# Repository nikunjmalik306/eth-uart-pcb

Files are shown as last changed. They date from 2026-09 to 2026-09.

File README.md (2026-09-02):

# ETH-UART PCB

An STM32-based Ethernet-to-UART development board designed in Autodesk EAGLE.

The board combines an STM32F407VE microcontroller with a DP83848 Ethernet PHY, RJ45 Ethernet interface, USB connectivity, multiple UART interfaces, SWD programming/debug access, status LEDs, test points, and selectable configuration jumpers.

## Features

- **MCU:** STM32F407VE
- **Ethernet PHY:** TI DP83848
- **Ethernet connector:** RJ45 with integrated magnetics
- **USB:** Micro-B connector
- **UART:** UART1, UART2, UART3 and UART5 signals
- **Debug/programming:** SWDIO and SWCLK
- **Clocks:** 8 MHz MCU oscillator and 25 MHz Ethernet PHY oscillator
- **Power:** 5 V input with 3.3 V regulation
- **Indicators:** Ethernet/activity/status LEDs
- **Test access:** IO and CLK test points
- **PCB size:** approximately **52 mm × 21 mm**
- **Design tool:** Autodesk EAGLE 9.6.2

## Repository Contents

```text
.
├── README.md
├── LICENSE
├── eth-uart.sch              # EAGLE schematic
├── eth-uart.brd              # EAGLE PCB layout
├── eagle.epf                 # EAGLE project file
└── doc/
    ├── img/
    │   ├── pcb_top.png
    │   └── pcb_bottom.png
    └── gerber/
        ├── copper_top.gbr
        ├── copper_bottom.gbr
        ├── soldermask_top.gbr
        ├── soldermask_bottom.gbr
        ├── silkscreen_top.gbr
        ├── silkscreen_bottom.gbr
        ├── profile.gbr
        ├── drills.xln
        └── project.gvp
```

## PCB Preview

### Top

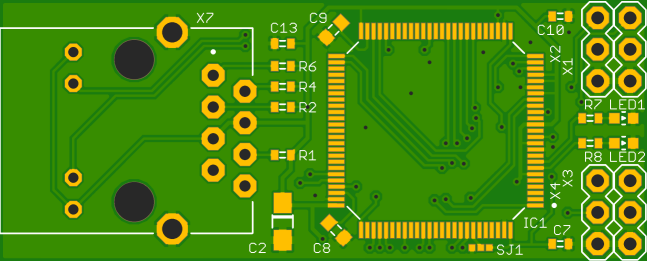
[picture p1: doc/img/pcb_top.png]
PCB top


### Bottom

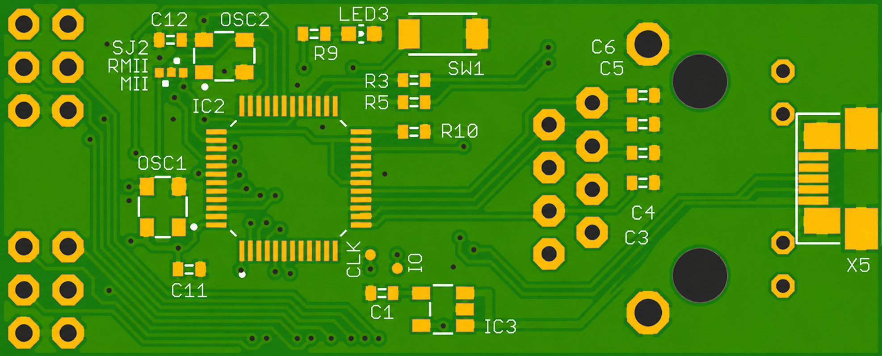
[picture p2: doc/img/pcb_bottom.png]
PCB bottom


## Main Interfaces

| Interface | Signals |
|---|---|
| Ethernet | TXDP, TXDM, RXDP, RXDM |
| Ethernet MAC | ETH_TXD0–ETH_TXD3, ETH_RXD0–ETH_RXD3, ETH_TX_EN, ETH_RX_DV, ETH_RX_CLK, ETH_TX_CLK, ETH_CRS, ETH_COL, ETH_MDC, ETH_MDIO |
| UART | UART1_TX/RX, UART2_TX/RX, UART3_TX/RX, UART5_TX/RX |
| USB FS | USB_FS_DP, USB_FS_DM |
| Debug | SWD_IO, SWD_CLK |
| Boot | BOOT0 |
| Clock | SYS_CLK, PHY_OSC |

## Opening the Design

Open the project with **Autodesk EAGLE 9.x** or a compatible version.

1. Open `eagle.epf`.
2. Open `eth-uart.sch` to inspect the schematic.
3. Open `eth-uart.brd` to inspect or modify the PCB layout.
4. Review the design rules, libraries, footprints, and component availability before manufacturing.

## Manufacturing

The `doc/gerber/` directory contains generated manufacturing files.

Before sending the files to a PCB manufacturer, verify:

- board outline/profile
- copper layers
- solder-mask layers
- silkscreen layers
- drill file
- fabrication tolerances and stack-up
- component footprints
- assembly requirements

> **Important:** This is an open hardware design. Always verify the schematic, PCB layout, component ratings, footprints, and manufacturing files before building or ordering hardware.

## Credits

**Project maintainer:** **Nikunj Malik**

GitHub: [@nikunjmalik306](https://github.com/nikunjmalik306)

The repository is maintained and published by Nikunj Malik under the MIT License.

## License

This project is licensed under the **MIT License**. See [`LICENSE`](LICENSE) for the complete license text.

SPDX-License-Identifier: MIT

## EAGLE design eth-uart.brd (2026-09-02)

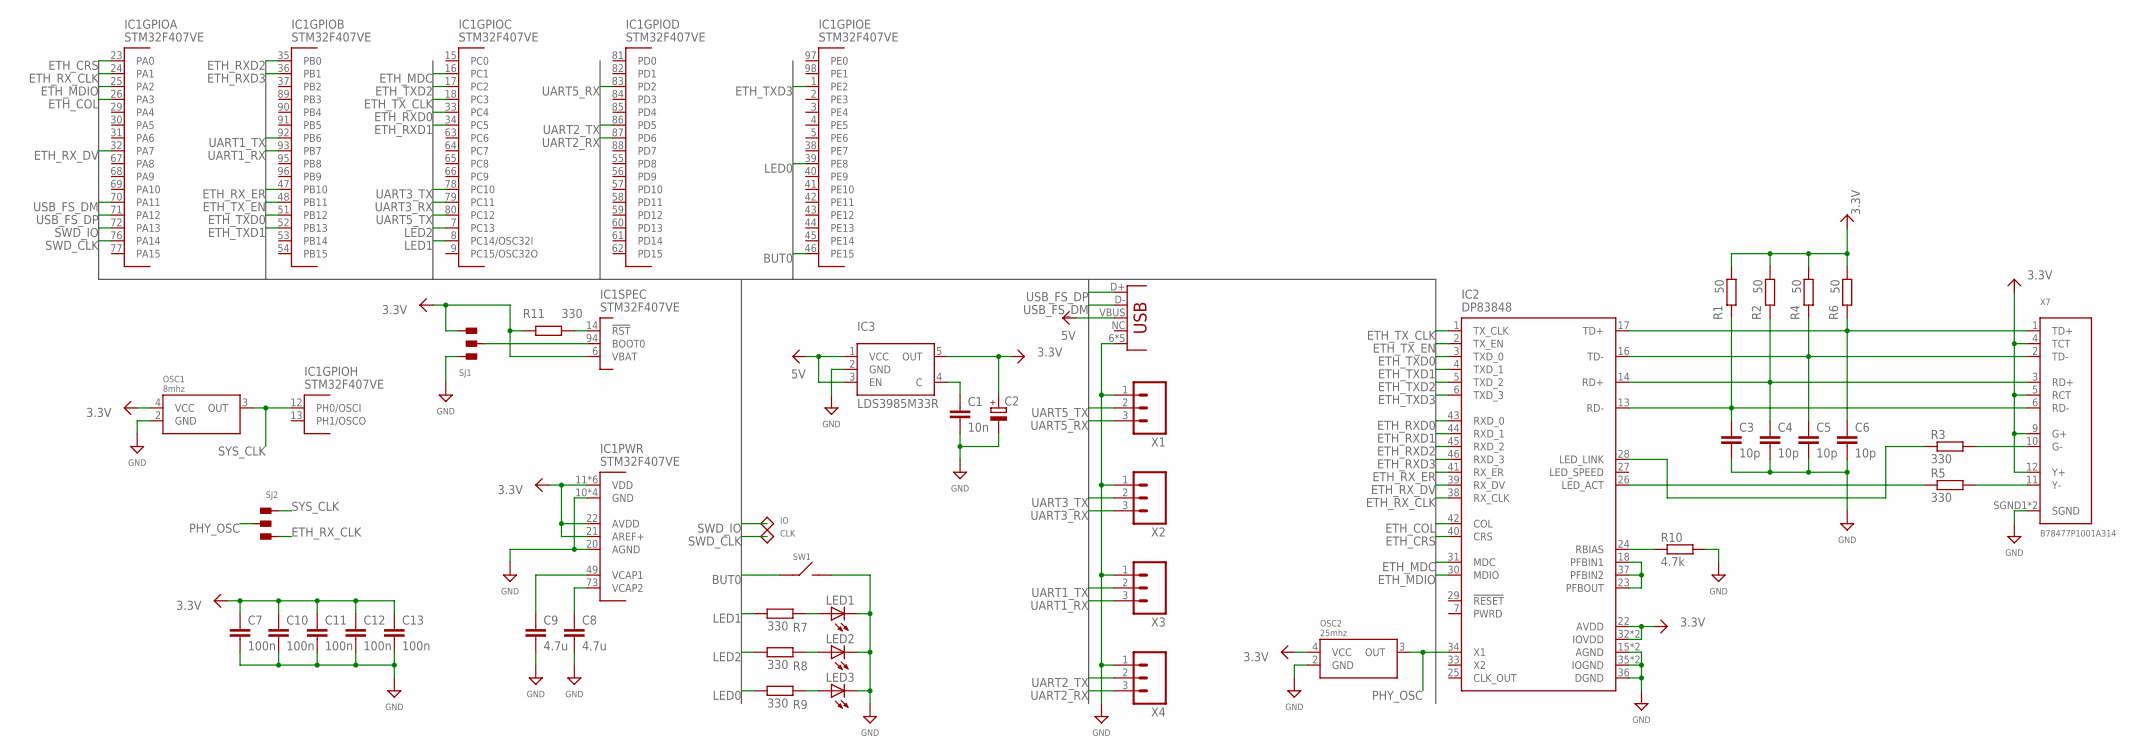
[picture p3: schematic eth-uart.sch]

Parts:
C1: 10n; R0402
C2: CPOL-EUSMCA; SMC_A
C3, C4, C5, C6: 10p; R0402
C7, C10, C11, C12, C13: 100n; R0402
C8, C9: 4.7u; R0603
IC1: STM32F407VE; LQFP100
IC2: DP83848; LQFP-48
IC3: LDS3985M33R; SOT23-5
LED1, LED2, LED3: LED0603
OSC1: 8mhz; 3225
OSC2: 25mhz; 3225
R1, R2, R4, R6: 50; R0402
R3, R5, R7, R8, R9, R11: 330; R0402
R10: 4.7k; R0402
SJ1, SJ2: SJ3
SW1: BUT; SONY_ERRICSON_SW
TP1: IO; TP06R
TP2: CLK; TP06R
X1, X2, X3, X4: M03; 1X03
X5: USBMICRO_B; USB_MICROB
X7: B78477P1001A314; HR911105A

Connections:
3.3V: C2.+, C7.1, C10.1, C11.1, C12.1, C13.1, IC1.6 (VBAT), IC1.11 (VDD), IC1.19 (VDD), IC1.21 (AREF+), IC1.22 (AVDD), IC1.28 (VDD), IC1.50 (VDD), IC1.75 (VDD), IC1.100 (VDD), IC2.22 (AVDD), IC2.32 (IOVDD), IC2.48 (IOVDD), IC3.5 (OUT), OSC1.4 (VCC), OSC2.4 (VCC), R1.1, R2.1, R4.1, R6.1, R11.1, SJ1.3, X7.4 (TCT), X7.5 (RCT), X7.9 (G+), X7.12 (Y+)
5V: IC3.1 (VCC), IC3.3 (EN), X5.VBUS
BOOT0: IC1.94 (BOOT0), SJ1.2
BUT0: IC1.46 (PE15), SW1.1
ETH_COL: IC1.26 (PA3), IC2.42 (COL)
ETH_CRS: IC1.23 (PA0), IC2.40 (CRS)
ETH_MDC: IC1.16 (PC1), IC2.31 (MDC)
ETH_MDIO: IC1.25 (PA2), IC2.30 (MDIO)
ETH_RXD0: IC1.33 (PC4), IC2.43 (RXD_0)
ETH_RXD1: IC1.34 (PC5), IC2.44 (RXD_1)
ETH_RXD2: IC1.35 (PB0), IC2.45 (RXD_2)
ETH_RXD3: IC1.36 (PB1), IC2.46 (RXD_3)
ETH_RX_CLK: IC1.24 (PA1), IC2.38 (RX_CLK), SJ2.3
ETH_RX_DV: IC1.32 (PA7), IC2.39 (RX_DV)
ETH_RX_ER: IC1.47 (PB10), IC2.41 (RX_ER)
ETH_TXD0: IC1.51 (PB12), IC2.3 (TXD_0)
ETH_TXD1: IC1.52 (PB13), IC2.4 (TXD_1)
ETH_TXD2: IC1.17 (PC2), IC2.5 (TXD_2)
ETH_TXD3: IC1.1 (PE2), IC2.6 (TXD_3)
ETH_TX_CLK: IC1.18 (PC3), IC2.1 (TX_CLK)
ETH_TX_EN: IC1.48 (PB11), IC2.2 (TX_EN)
GND: C1.2, C2.-, C3.2, C4.2, C5.2, C6.2, C7.2, C8.2, C9.2, C10.2, C11.2, C12.2, C13.2, IC1.10 (GND), IC1.20 (AGND), IC1.27 (GND), IC1.74 (GND), IC1.99 (GND), IC2.15 (AGND), IC2.19 (AGND), IC2.35 (IOGND), IC2.36 (DGND), IC2.47 (IOGND), IC3.2 (GND), LED1.C, LED2.C, LED3.C, OSC1.2 (GND), OSC2.2 (GND), R10.2, SJ1.1, SW1.2, X1.1, X2.1, X3.1, X4.1, X5.6 (GND), X5.7 (GND), X5.8 (GND), X5.9 (GND), X5.GND, X7.SGND1 (SGND), X7.SGND2 (SGND)
LED0: IC1.39 (PE8), R9.1
LED1: IC1.8 (PC14/OSC32I), R7.1
LED2: IC1.7 (PC13), R8.1
LED_ACT: IC2.26 (LED_ACT), R5.1
LED_G: R3.2, X7.10 (G-)
LED_LINK: IC2.28 (LED_LINK), R3.1
LED_Y: R5.2, X7.11 (Y-)
unnamed: IC1.14 (!RST), R11.2
unnamed: IC2.18 (PFBIN1), IC2.23 (PFBOUT), IC2.37 (PFBIN2)
unnamed: C1.1, IC3.4 (C)
unnamed: LED1.A, R7.2
unnamed: LED2.A, R8.2
unnamed: LED3.A, R9.2
unnamed: IC2.24 (RBIAS), R10.1
unnamed: C8.1, IC1.73 (VCAP2)
unnamed: C9.1, IC1.49 (VCAP1)
PHY_OSC: IC2.34 (X1), OSC2.3 (OUT), SJ2.2
RXDM: C3.1, IC2.13 (RD-), R1.2, X7.6 (RD-)
RXDP: C4.1, IC2.14 (RD+), R2.2, X7.3 (RD+)
SWD_CLK: IC1.76 (PA14), TP2.TP
SWD_IO: IC1.72 (PA13), TP1.TP
SYS_CLK: IC1.12 (PH0/OSCI), OSC1.3 (OUT), SJ2.1
TXDM: C5.1, IC2.16 (TD-), R4.2, X7.2 (TD-)
TXDP: C6.1, IC2.17 (TD+), R6.2, X7.1 (TD+)
UART1_RX: IC1.93 (PB7), X3.3
UART1_TX: IC1.92 (PB6), X3.2
UART2_RX: IC1.87 (PD6), X4.3
UART2_TX: IC1.86 (PD5), X4.2
UART3_RX: IC1.79 (PC11), X2.3
UART3_TX: IC1.78 (PC10), X2.2
UART5_RX: IC1.83 (PD2), X1.3
UART5_TX: IC1.80 (PC12), X1.2
USB_FS_DM: IC1.70 (PA11), X5.D-
USB_FS_DP: IC1.71 (PA12), X5.D+

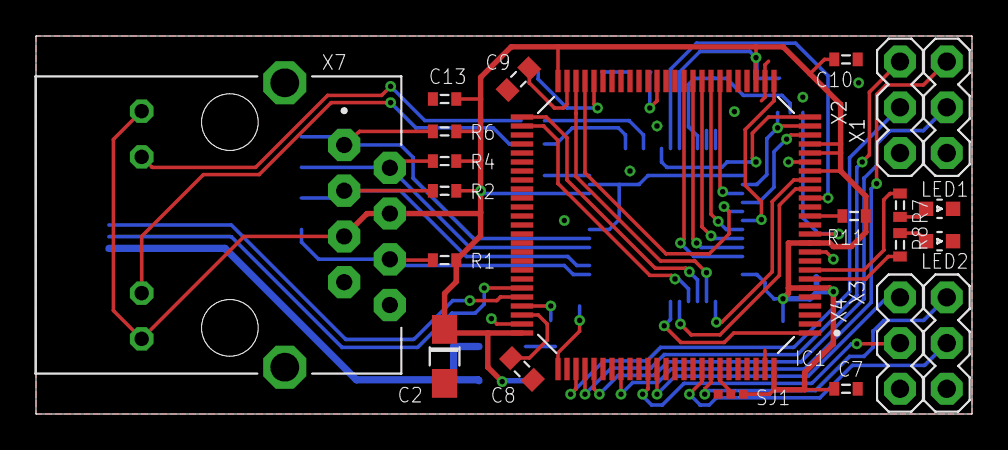
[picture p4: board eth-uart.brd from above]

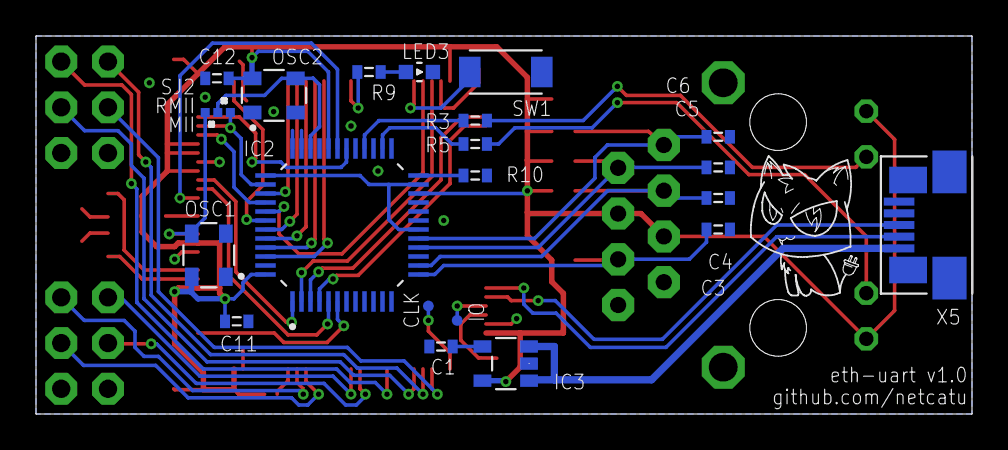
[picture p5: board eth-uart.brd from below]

Board: 2 copper layers, 52.0 x 21.0 mm, 44 parts (22 on the bottom side), 56 nets.

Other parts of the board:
U$1: LOGO2
